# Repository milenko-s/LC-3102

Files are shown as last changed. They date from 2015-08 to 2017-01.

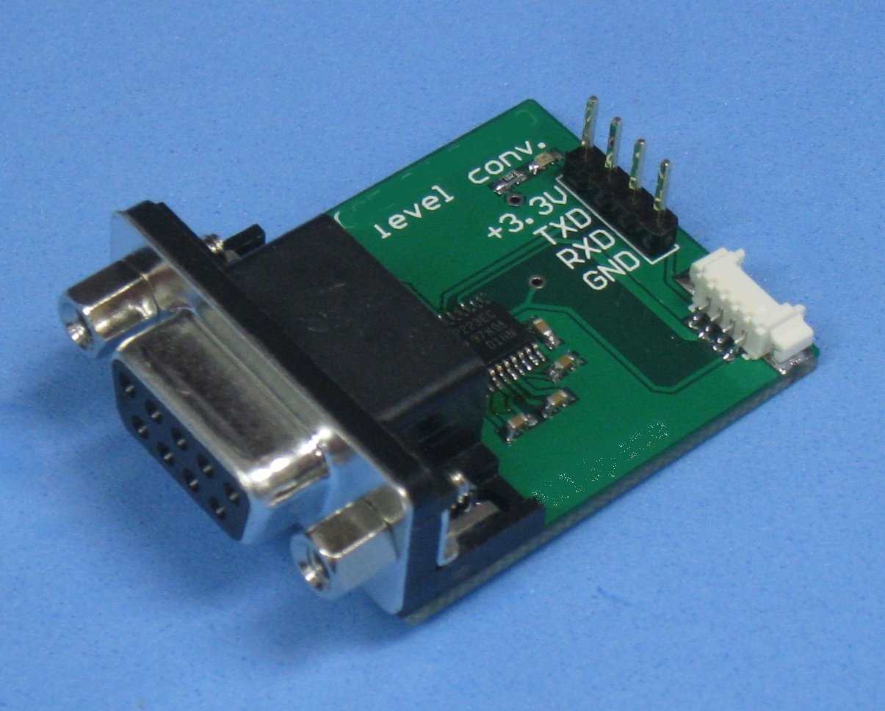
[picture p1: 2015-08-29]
documentation/pictures/IMG_1882.JPG

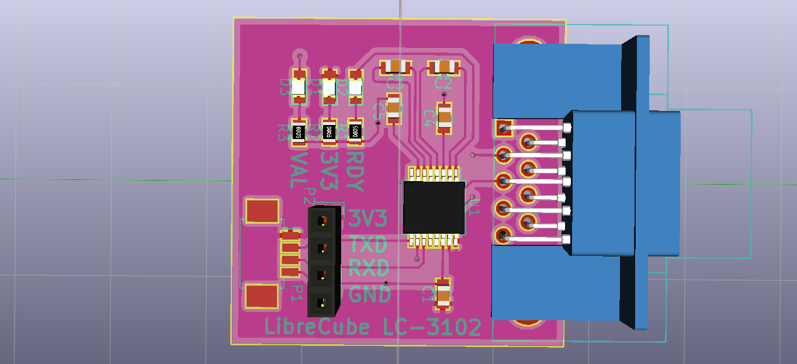
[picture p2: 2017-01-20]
documentation/pictures/uart_adapter.png

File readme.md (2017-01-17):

# LibreCube LC-3102 UART Adapter

## About

The UART Adapter is used to connect the UART bus from a microcontroller to the RS232 (serial port) interface of a computer. 

## Authors

- Artur Scholz [artur.scholz@librecube.net]
- Milenko Starcik [-]

## Acknowledgements

- Development supported from National Cheng Kung University (www.ncku.edu.tw) under supervision of Prof. Jiun-Jih Miau and Prof. Jyh-Ching Juang and with the help from students of PACELAB and MECLAB.

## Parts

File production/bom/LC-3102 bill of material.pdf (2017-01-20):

LC-3102 BOM

Reference | Value | Footprint | Quantity | Vendor | Part Number | Unit Cost | Total Cost
J1 | DB9 | Connectors:DB9FC | 1 Digi-Key | | A35107-ND | 1,31 € | 1,31 €
C1,C2,C3,C4,C5 | 0.1uF | Capacitors_SMD:C_0805_HandSoldering | 5 Digi-Key | | 478-3352-1-ND | 0,10 € | 0,50 €
P1 | CONN_01X04 | Connectors_Molex:Molex_PicoBlade_53261-0471_04x1.25mm_Angled | 1 Digi-Key | | WM7622CT-ND | 1,31 € | 1,31 €
R1,R2,R3 | 1.5k | Resistors_SMD:R_0805_HandSoldering | 3 Digi-Key | | 311-1.50KCRCT-ND | 0,10 € | 0,30 €
U1 | MAX3227 | Housings_SSOP:SSOP-16_5.3x6.2mm_Pitch0.65mm | 1 Digi-Key | | 296-19849-1-ND | 2,63 € | 2,63 €
P2 | CONN_01X04 | Socket_Strips:Socket_Strip_Straight_1x04 | 1 Digi-Key | | 609-3305-ND | 0,19 € | 0,19 €
D1 | LED_Small | LEDs:LED_0805 | 1 Digi-Key | | 475-1415-1-ND | 0,25 € | 0,25 €
D2 | LED_Small | LEDs:LED_0805 | 1 Digi-Key | | 475-2560-1-ND | 0,26 € | 0,26 €
D3 | LED_Small | LEDs:LED_0805 | 1 Digi-Key | | 475-1410-1-ND | 0,25 € | 0,25 €
Total: | 7,00 €

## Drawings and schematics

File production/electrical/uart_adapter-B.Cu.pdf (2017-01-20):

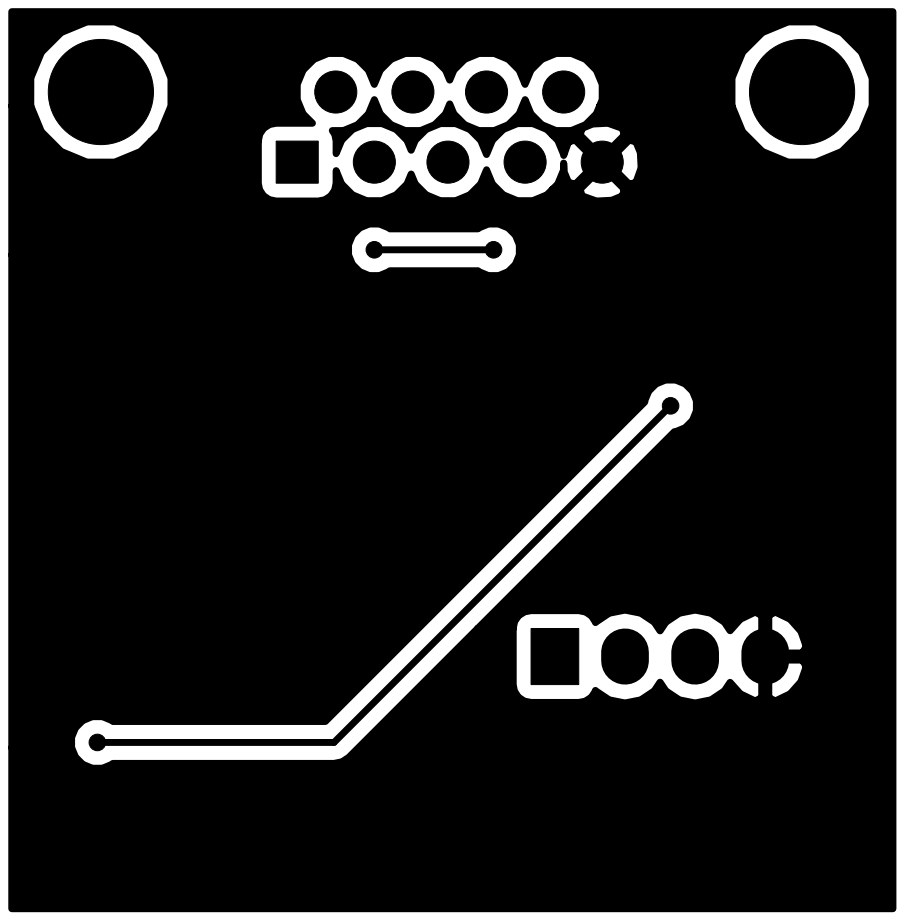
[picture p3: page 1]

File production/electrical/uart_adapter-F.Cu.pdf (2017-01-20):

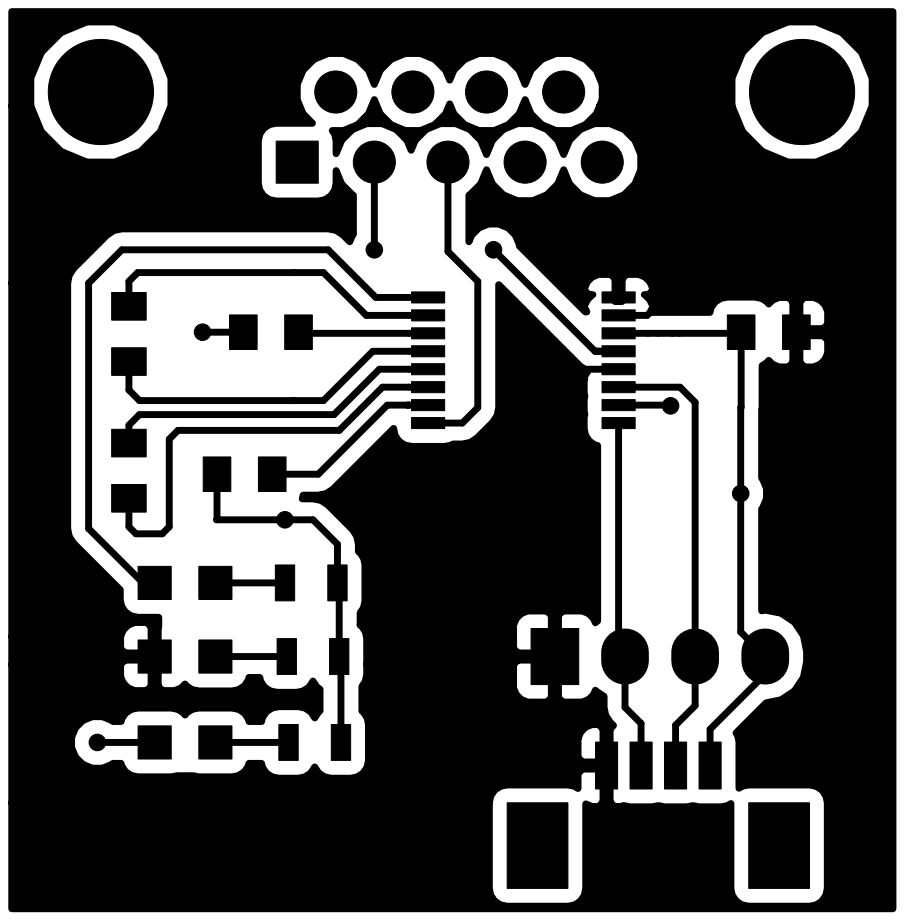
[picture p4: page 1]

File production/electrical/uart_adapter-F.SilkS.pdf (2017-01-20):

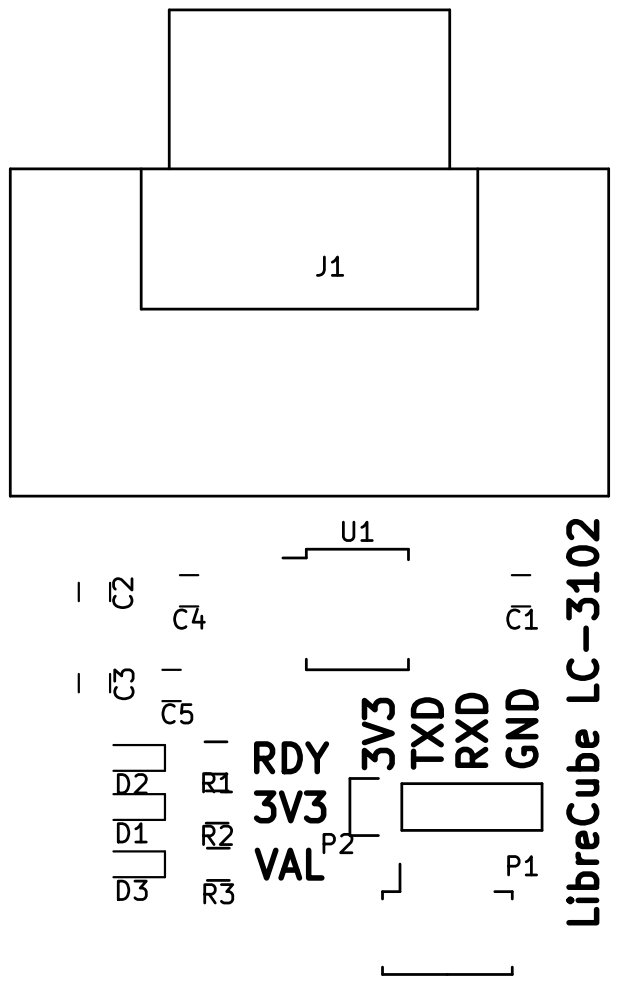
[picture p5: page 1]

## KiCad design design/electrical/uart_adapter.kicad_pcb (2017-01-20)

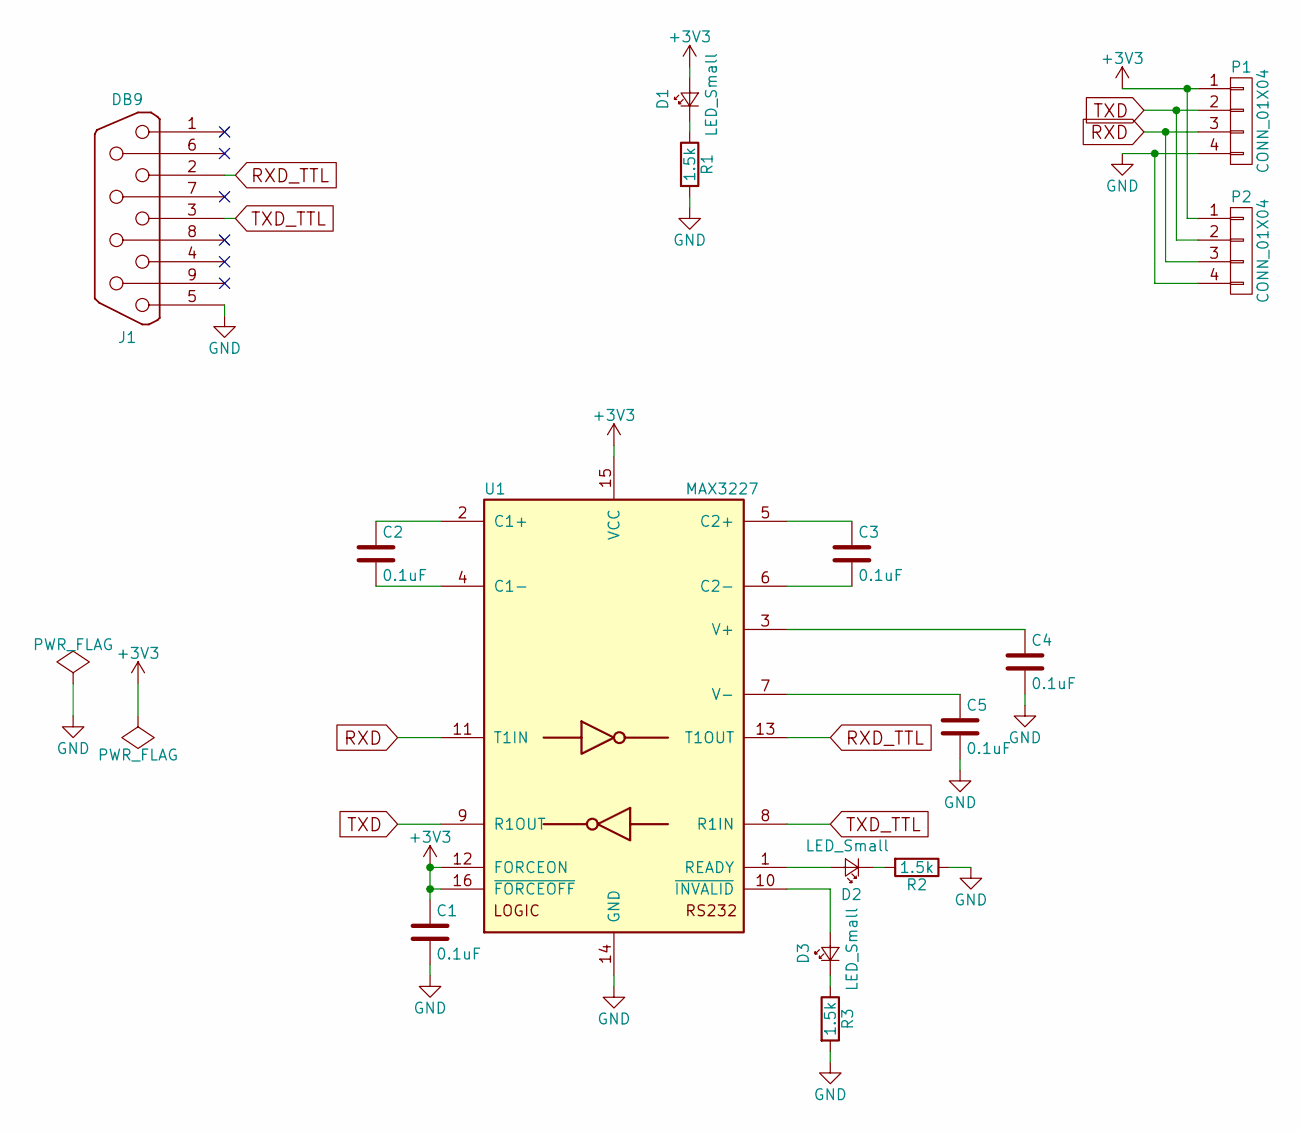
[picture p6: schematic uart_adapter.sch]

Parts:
C1, C2, C3, C4, C5: 0.1uF; C_0805_HandSoldering
D1, D2, D3: LED_Small; LED_0805
J1: DB9; DB9FC
P1: CONN_01X04; Molex_PicoBlade_53261-0471_04x1.25mm_Angled
P2: CONN_01X04; Socket_Strip_Straight_1x04
R1, R2, R3: 1.5k; R_0805_HandSoldering
U1: MAX3227; SSOP-16_5.3x6.2mm_Pitch0.65mm

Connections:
+3V3: C1.1, D1.2 (A), P1.1, P2.1, U1.12 (FORCEON), U1.15 (VCC), U1.16 (~FORCEOFF)
GND: C1.2, C4.2, C5.2, J1.5, P1.4, P2.4, R1.2, R2.1, R3.2, U1.14 (GND)
unnamed: C2.1, U1.2 (C1+)
unnamed: C2.2, U1.4 (C1-)
unnamed: C3.1, U1.5 (C2+)
unnamed: C3.2, U1.6 (C2-)
unnamed: C4.1, U1.3 (V+)
unnamed: C5.1, U1.7 (V-)
unnamed: D1.1 (K), R1.1
unnamed: D2.1 (K), R2.2
unnamed: D2.2 (A), U1.1 (READY)
unnamed: D3.1 (K), R3.1
unnamed: D3.2 (A), U1.10 (~INVALID)
RXD: P1.3, P2.3, U1.11 (T1IN)
RXD_TTL: J1.2, U1.13 (T1OUT)
TXD: P1.2, P2.2, U1.9 (R1OUT)
TXD_TTL: J1.3, U1.8 (R1IN)

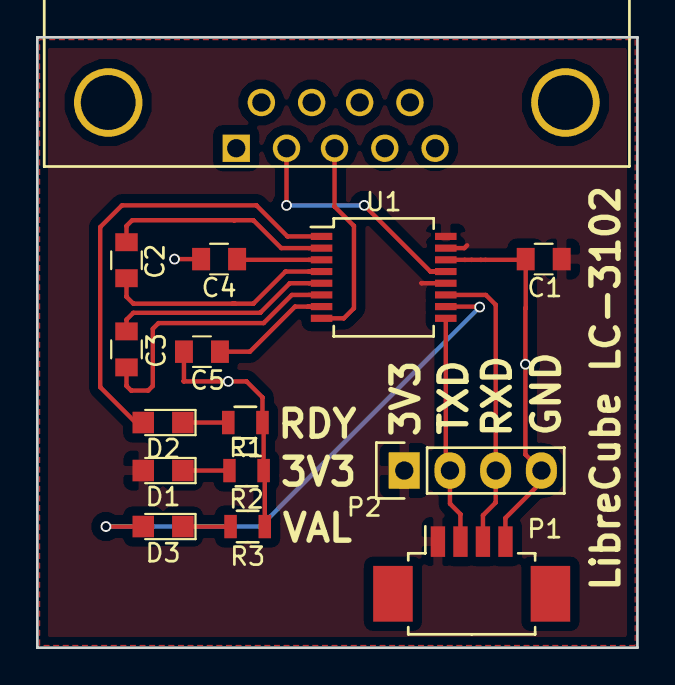
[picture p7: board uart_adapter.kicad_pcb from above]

Board: 2 copper layers, 33.3 x 33.9 mm, 15 parts (0 on the bottom side), 17 nets.

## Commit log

2016-05-22 mod: remove non-free source files
    [main.SchDoc, pcb.PCBDOC]
2017-01-14 Started PCB design
    [UART_Adapter.sch]
2017-01-16 Added Molex connector
    [uart_adapter.kicad_pcb, uart_adapter.sch]
2017-01-18 Created power and ground plane
2017-01-20 3D-View in KiCad
2017-01-20 New bom files
    [LC-3102 bill of material.ods]
2017-01-20 Outline changed
    [uart_adapter.kicad_pcb]
2017-01-20 New gerber files
    [pcb.DRL, pcb.GBL, pcb.GBS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]
